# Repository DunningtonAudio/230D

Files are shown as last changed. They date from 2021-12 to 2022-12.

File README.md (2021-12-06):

# 230D
A triple envelope follower project

The 230D Triple Envelope Follower is designed to replicate the functionality of the Buchla 230A module using modern construction techniques and readily available parts. It is primarily based on the original circuit designed by Don Buchla, with the following additions/alterations:

* Proper current limiting implemented for pulse output LEDs, increasing LED life and preventing crosstalk between channels
* Pulse/gate output voltages adjusted to 10V/5V
* Pulse outputs are buffered, protecting the passive pulse generation network from the effects of loading when stacking one output to multiple destinations
* Pulse outputs are designed to allow stacking of multiple outputs to a single input, whilst also being able to drive a floating input low.

The repository contains:

* KiCad project files
* Schematic and build/calibration notes as PDF files
* Bill of Materials in ODS and PDF format
* Interactive webpage for matching BOM items to PCB locations

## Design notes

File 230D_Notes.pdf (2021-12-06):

230D Triple Envelope Follower

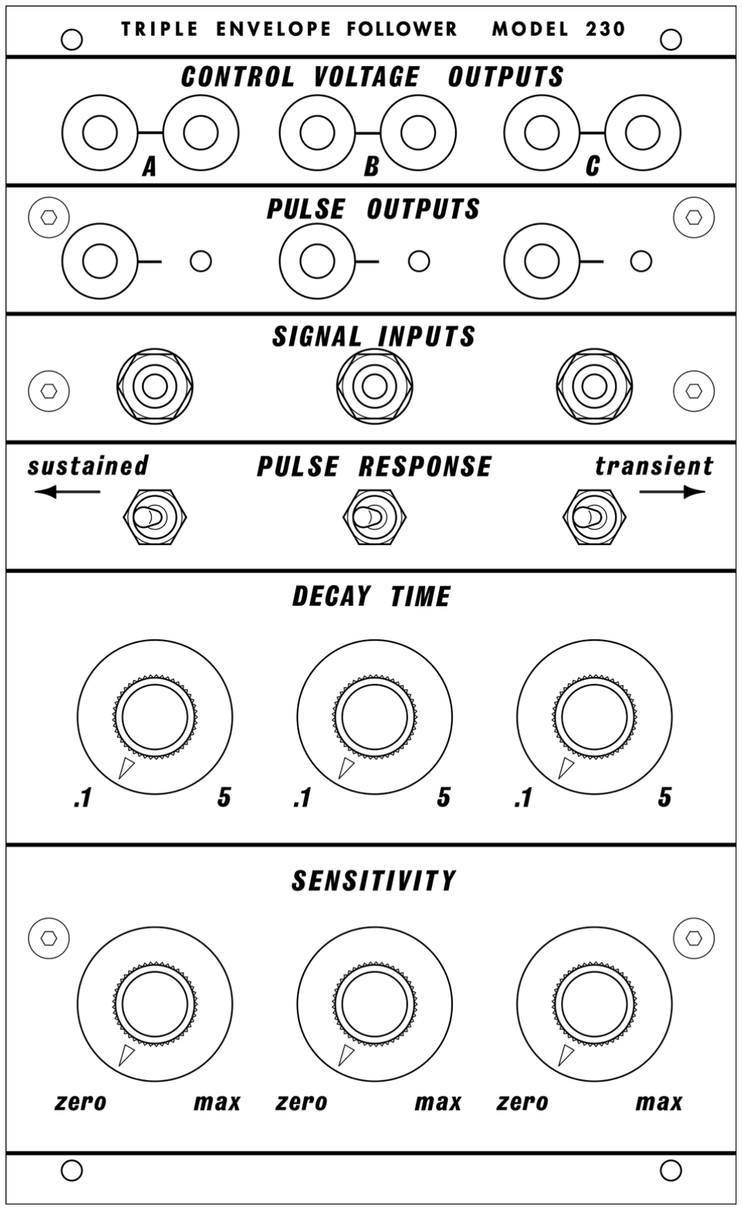
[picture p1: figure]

The 230D Triple Envelope Follower is designed to replicate the functionality of the Buchla 230A module using modern construction techniques and readily available parts. It is primarily based on the original circuit designed by Don Buchla, with the following additions/alterations:

- Proper current limiting implemented for pulse output LEDs, increasing LED life and preventing crosstalk between channels
- Pulse/gate output voltages adjusted to 10V/5V
- Pulse outputs are buffered, protecting the passive pulse generation network from the effects of loading when stacking one output to multiple destinations
- Pulse outputs are designed to allow stacking of multiple outputs to a single input, whilst also being able to drive a floating input low.

Build Notes:

** The 230D is designed to be suitable for hand assembly, but it is not recommended as a “learn surface mount” starting point. You should at a minimum have a temperature controlled soldering iron with a reasonably fine point and good quality solder 0.5mm diameter or finer. Some form of magnification may be beneficial for placing/inspecting fine pitch parts. **

It is recommended that the circuit board is populated in the following order:

- SOT-23 packages
- SOIC packages
- 0805 passives
- Trimmer potentiometers
- Tantalum chip capacitors
- Electrolytic capacitors
- Power wiring harness

Connectors should have their wire links attached and be mounted to the front panel, along with standoffs. Front panel potentiometers, switches and LEDs can then be loosely fitted into the PCB and the panel and PCB brought together before gently tightening the potentiometer and switch fixing nuts and soldering the panel components and connections.

Calibration procedure:

Equipment required:
- Power supply delivering +/- 15V and +12V, current limit at 20mA
- Signal generator
- DC Voltmeter
- Oscilloscope
1. Set front panel controls as follows:
- VR101/201/301 Sensitivity – Fully CCW
- VR102/202/302 Decay Time – Fully CCW
- SW101/201/301 Pulse Response – Transient
2. Set trimpots as follows (direction as viewed from the rear of the module):
- TR101/201/301 Offset – Centre
3. Apply power to the module and check for approx 10mA current draw on the +/- 15V rails, 0mA on the 12V rail.

The following steps should be repeated for each channel:

4. Allow the module to warm up. Connect the DC Voltmeter to the CV output of the channel under test and adjust the OFFSET trimpot for 0V DC at the output (note that the circuit is very sensitive, it may be beneficial to apply averaging to the reading).
5. Set the signal generator to produce a 1kHz, 1V peak to peak sine wave, connect this to the input of the channel under test, and monitor the CV output with the voltmeter. Adjust the sensitivity control for 10V DC at the CV output. Monitor the pulse output on the oscilloscope. Switch the pulse response to sustained and check that a brief ~10V pulse is produced before the output settles at a constant ~5V DC. Switch the response back to transient and check that the pulse output returns to 0V.
6. Monitor the control voltage output on the oscilloscope. Switch off the output of the signal generator and check that the fall time is approx. 100ms. Switch the signal generator back on, set the decay time control fully CW. Check that the CV output is still 10V DC and adjust the sensitivity if necessary. Switch off the signal generator and check that the fall time is approx. 5s.

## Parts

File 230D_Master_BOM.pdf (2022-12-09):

230D_1.2_Master

Reference | Quantity | Value | Footprint | Manufacturer | MPN | Supplier | Order Code | Description | Notes

PCB Mount
C105 C107 C205 C207 C305 C307 | 6 | 100p | C0805 | Yageo | CC0805JRNPO9BN101 | Mouser | 603-CC805JRNPO9BN101 | C0G, 50V, 5%
C106 C109 C206 C209 C306 C309 | 6 | 47n | C0805 | Yageo | CC0805JRNPO9BN221 | Mouser | 603-CC805KRX7R9BB473 | X7R, 50V, 10%
C102-103 C110-111 C202-203 C210-211 C302-303 C310-311 | 12 | 100n | C0805 | Yageo | CC0805KRX7R9BB104 | Mouser | 603-CC805KRX7R9BB104 | X7R, 50V, 10%
C101 C104 C201 C204 C301 C304 | 6 | 1u | CE4x5.8 | Panasonic | EEE-FC1V1R0AR | Mouser | 667-EEE-FC1V1R0AR | 35V, 20%, 105deg
C108 C208 C308 | 3 | 4u7 | C1210 (B) | AVX | TAJB475K035RNJ | Mouser | 581-TAJB475K035R | 35V, 10%, 125deg
C1 C2 C3 | 3 | 22u | CE5x5.8 | Panasonic | EEE-FK1V220AR | Mouser | 667-EEE-FK1V220AR | 35V, 20%, 105deg
D101 D201 D301 | 3 | SZMM3Z3V9ST1G | SOD-323 | On Semiconductor | SZMM3Z3V9ST1G | Mouser | 863-SZMM3Z3V9ST1G | Zener diode, 3.9V, 300mW
D102, D202, D302 | 3 | BAV99 | SOT-23-3 | On Semiconductor | BAV99LT1G | Mouser | 863-BAV99LT1G | Dual diode, series, 215mA
D103, D105, D203, D205, D303, D305 | 6 | BAS16 | SOT-23-3 | On Semiconductor | BAS16LT1G | Mouser | 863-BAS16LT1G | Diode, 200mA
D104, D204, D304 | 3 | Red_3mm | 3mm LED THT | Wurth Elektronik | 151031SS04000 | Mouser | 710-151031SS04000 | LED red 3mm 635nm 160mcd
L1 L2 L3 | 3 | 10u | L0805 | Taiyo Yuden | LBC2012T100K | Mouser | 963-LBC2012T100K | 1.2R, 200mA, 10%
Q101 Q201 Q301 | 3 | MMBT3904 | SOT-23-3 | On Semiconductor | MMBT3904LT1G | Mouser | 863-MMBT3904LT1G | NPN
R123 R129 R223 R229 R323 R329 | 6 | 1k | R0805 | Yageo | RC0805FR-071KL | Mouser | 603-RC0805FR-071KL | 150V, 125mW, 1%, 100PPM
R102 R124 R202 R224 R302 R324 | 6 | 4k7 | R0805 | Yageo | RC0805FR-074K7L | Mouser | 603-RC0805FR-074K7L | 150V, 125mW, 1%, 100PPM
R122 R125 R222 R225 R322 R325 | 6 | 6k8 | R0805 | Yageo | RC0805FR-076K8L | Mouser | 603-RC0805FR-076K8L | 150V, 125mW, 1%, 100PPM
R126 R128 R226 R228 R326 R328 | 6 | 10k | R0805 | Yageo | RC0805FR-0710KL | Mouser | 603-RC0805FR-0710KL | 150V, 125mW, 1%, 100PPM
R118 R127 R218 R227 R318 R327 | 6 | 11k | R0805 | Yageo | RC0805FR-0711KL | Mouser | 603-RC0805FR-0711KL | 150V, 125mW, 1%, 100PPM
R111 R119 R211 R219 R311 R319 | 6 | 15k | R0805 | Yageo | RC0805FR-0715KL | Mouser | 603-RC0805FR-0715KL | 150V, 125mW, 1%, 100PPM
R106-109 R112-113 R121 R206-209 R212-213 R221 R306-309 R312-313 R321 | 21 | 33k | R0805 | Yageo | RC0805FR-0733KL | Mouser | 603-RC0805FR-0733KL | 150V, 125mW, 1%, 100PPM
R114 R117 R214 R217 R314 R317 | 6 | 68k | R0805 | Yageo | RC0805FR-0768KL | Mouser | 603-RC0805FR-0768KL | 150V, 125mW, 1%, 100PPM
R120 R220 R320 | 3 | 100k | R0805 | Yageo | RC0805FR-07100KL | Mouser | 603-RC0805FR-07100KL | 150V, 125mW, 1%, 100PPM
R101 R201 R301 | 3 | 150k | R0805 | Yageo | RC0805FR-07150KL | Mouser | 603-RC0805FR-07150KL | 150V, 125mW, 1%, 100PPM
R105 R116 R205 R216 R305 R316 | 6 | 330k | R0805 | Yageo | RC0805FR-07330KL | Mouser | 603-RC0805FR-07330KL | 150V, 125mW, 1%, 100PPM
R115 R215 R315 | 3 | 4M7 | R0805 | Yageo | RC0805FR-074M7L | Mouser | 603-RC0805FR-074M7L | 150V, 125mW, 1%, 100PPM
R103 R110 R203 R210 R303 R310 | 6 | 10M | R0805 | Yageo | RC0805FR-0710ML | Mouser | 603-RC0805FR-0710ML | 150V, 125mW, 1%, 100PPM
R104, R204, R304 | 3 | 22M | R0805 | Yageo | RC0805JR-0722ML | Mouser | 603-RC0805JR-0722ML | 150V, 125mW, 5%, 200PPM
SW101 SW201 SW301 | 3 | SPDT_ON-ON | M201X | NKK | M2012SS1W01 | Mouser | 633-M201201 | Toggle switch SPDT On-On
TR101 TR201 TR301 | 3 | 5k | 3314J | Bourns | 3314J-1-502E | Mouser | 652-3314J-1-502E | 500V,250mW, 20%, 100PPM
U101, U201, U301 | 3 | LM348 | SOIC14 | Texas Instruments | LM348DR | Mouser | 595-LM348DR | Quad operational amplifier, BJT input
U102, U202, U302 | 3 | LM321 | SOT-23-5 | Texas Instruments | LM321MF/NOPB | Mouser | 926-LM321MF/NOPB | Operational amplifier, BJT input
VR101 VR201 VR301 | 3 | 50kA | RV16AF-41-(L)R1-XXX | Alpha | RV16AF-41-15R1-503A | Small Bear | 1011 A50K | 16mm RA PCB mount potentiometer | Snap off locating lug
VR102 VR202 VR302 | 3 | 1MA | RV16AF-41-(L)R1-XXX | Alpha | RV16AF-41-15R1-105A | Small Bear | 1011 A1M | 16mm RA PCB mount potentiometer | Snap off locating lug
| 6 | | | McMaster-Carr | 93925A422 | McMaster | 93925A422 | M7 Shakeproof Washer | Fit between 16mm potentiometers and panel. Order code is for 100.

Panel Mount

J103-104 J203-204 J303-304 | 6 | CV Outputs | Johnson | 108-0910-001 | Mouser | 530-108-0910-1 | Blue banana jack
J102 J202 J302 | 3 | Pulse Outputs | Johnson | 108-0902-001 | Mouser | 530-108-0902-1 | Red banana jack
J101 J201 J301 | 3 | Audio Inputs | Switchcraft | 41 | Mouser | 502-41 | Tinijax
24awg wire black 25mm length | 3 | | Alpha Wire | 892419 BK005 | Mouser | 602-892419-100-02 | Wiring to audio shields | Strip 4mm each end. Order code is for 30.5m reel.
24awg wire white 25mm length | 3 | | Alpha Wire | 892419 WH005 | Mouser | 602-892419-100-01 | Wiring to audio inputs | Strip 4mm each end. Order code is for 30.5m reel.
24awg wire blue 25mm length | 6 | | Alpha Wire | 892419 BL005 | Mouser | 602-892419-100-06 | Wiring to CV outputs | Strip 4mm each end. Order code is for 30.5m reel.
24awg wire red 25mm length | 3 | | Alpha Wire | 892419 RD005 | Mouser | 602-892419-100-03 | Wiring to pulse outputs | Strip 4mm each end. Order code is for 30.5m reel.

Hardware & Misc

PCB | 1 | | Dunnington Audio | | thebeast.co.uk | http://thebeast.co.uk/?product=230d-triple-envelope-follower-pcb
Front panel | 1 | | The Beast | | thebeast.co.uk | http://thebeast.co.uk/?product=buchla-style-230-panel-reprint
M3x14mm F-F Standoff | 6 | | Harwin | R30-1001402 | Mouser | 855-R30-1001402
M3x6mm Philips CSK | 6 | | McMaster-Carr | 91801A151 | McMaster | 91801A151 | | Panel to standoff fixing. Order code is for 100.
M3x6mm Philips Pan SEMS | 6 | | McMaster-Carr | 90460A101 | McMaster | 90460A101 | | PCB to standoff fixing. Order code is for 25.
M3 Shakeproof Washer | 6 | | McMaster-Carr | 93925A417 | McMaster | 93925A417 | | Fit between standoffs and panel. Order code is for 100.
Small Skirted Knob | 6 | | Rogan | RB67-0-SK | Thonk | https://www.thonk.co.uk/shop/rogan-buchla/ | | Fit on all 16mm potentiometers
Switch Cap Red | 3 | | Thonk | | Thonk | https://www.thonk.co.uk/shop/switchcaps-mini/ | | Fit on SW101, SW201, SW301
J1 | 1 | Power | EDAC | 306-010-500-102 | Mouser | 587-306-50-010 | 10P edge connector, 3.96mm
| 1 | | EDAC | 338-240-328 | Mouser | 587-338-240-328 | Polarizing key | Fit in position 7 of power EDAC
20awg wire black 350mm length | 1 | Q | Alpha Wire | 892019 BK005 | Mouser | 602-892019-100-02 | | EDAC position 1. Order code is for 30.5m reel.
20awg wire white 350mm length | 1 | -15V | Alpha Wire | 892019 WH005 | Mouser | 602-892019-100-01 | | EDAC position 2. Order code is for 30.5m reel.
20awg wire red 350mm length | 1 | +15V | Alpha Wire | 892019 RD005 | Mouser | 602-892019-100-03 | | EDAC position 3. Order code is for 30.5m reel.
20awg wire green 350mm length | 1 | +12V | Alpha Wire | 892019 GR005 | Mouser | 602-892019-100-04 | | EDAC position 4. Order code is for 30.5m reel.
20awg wire brown 350mm length | 1 | N | Alpha Wire | 892019 BR005 | Mouser | 602-892019-100-07 | | EDAC position 6. Order code is for 30.5m reel.
Expandable Sleeving 6mm 300mm | 1 | | Alpha Wire | GRP1301/4 BK007 | Mouser | 602-130014-50BK | | Fit over power cabling. Order code is for 15.25m reel.
Heatshrink 6.35mm 40mm length | 2 | | Alpha Wire | FIT221V1/4 BK103 | Mouser | 602-221V014-4 | | Fit at each end of expandable sleeving
Heatshrink 3.18mm 12mm length | 5 | | Alpha Wire | FIT221V1/8 BK103 | Mouser | 602-221V018-4 | | Fit over terminated EDAC contacts
Cable ties | 2 | | Panduit | PLT.7M-M | Mouser | 644-PLT.7M-M | | Secure power cabling to PCB and EDAC

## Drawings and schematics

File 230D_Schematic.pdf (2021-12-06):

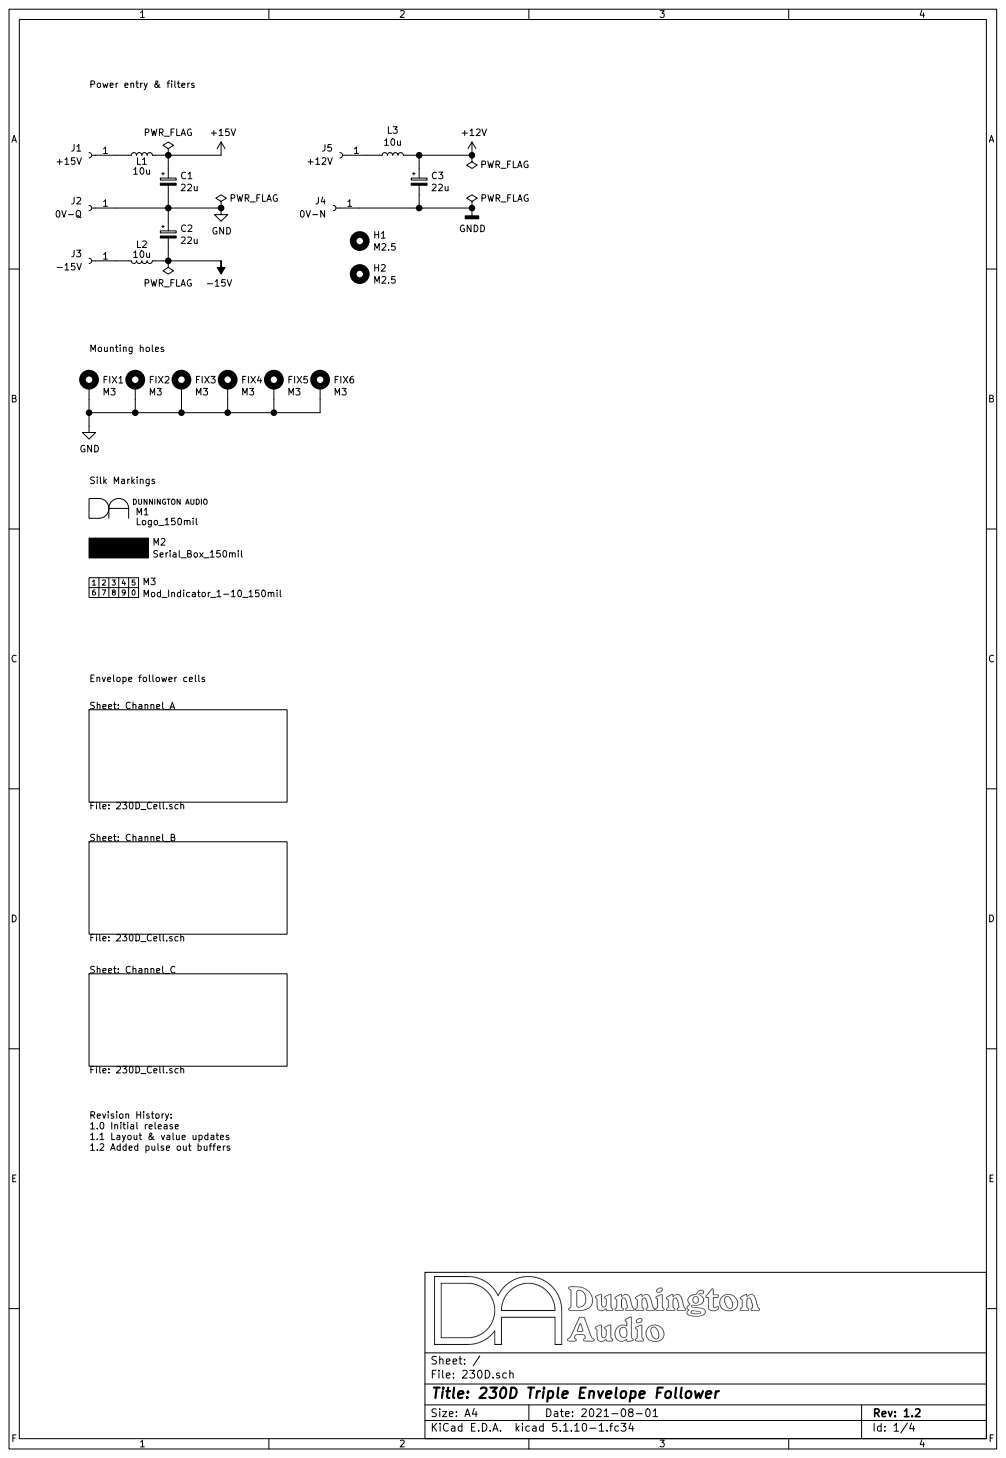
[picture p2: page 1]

Id: 1/4 Title: 230D Triple Envelope Follower File: 230D.sch Sheet: / Sheet: Channel_C

Revision History: 1.0 Initial release

1.1 Layout & value updates
1.2 Added pulse out buffers

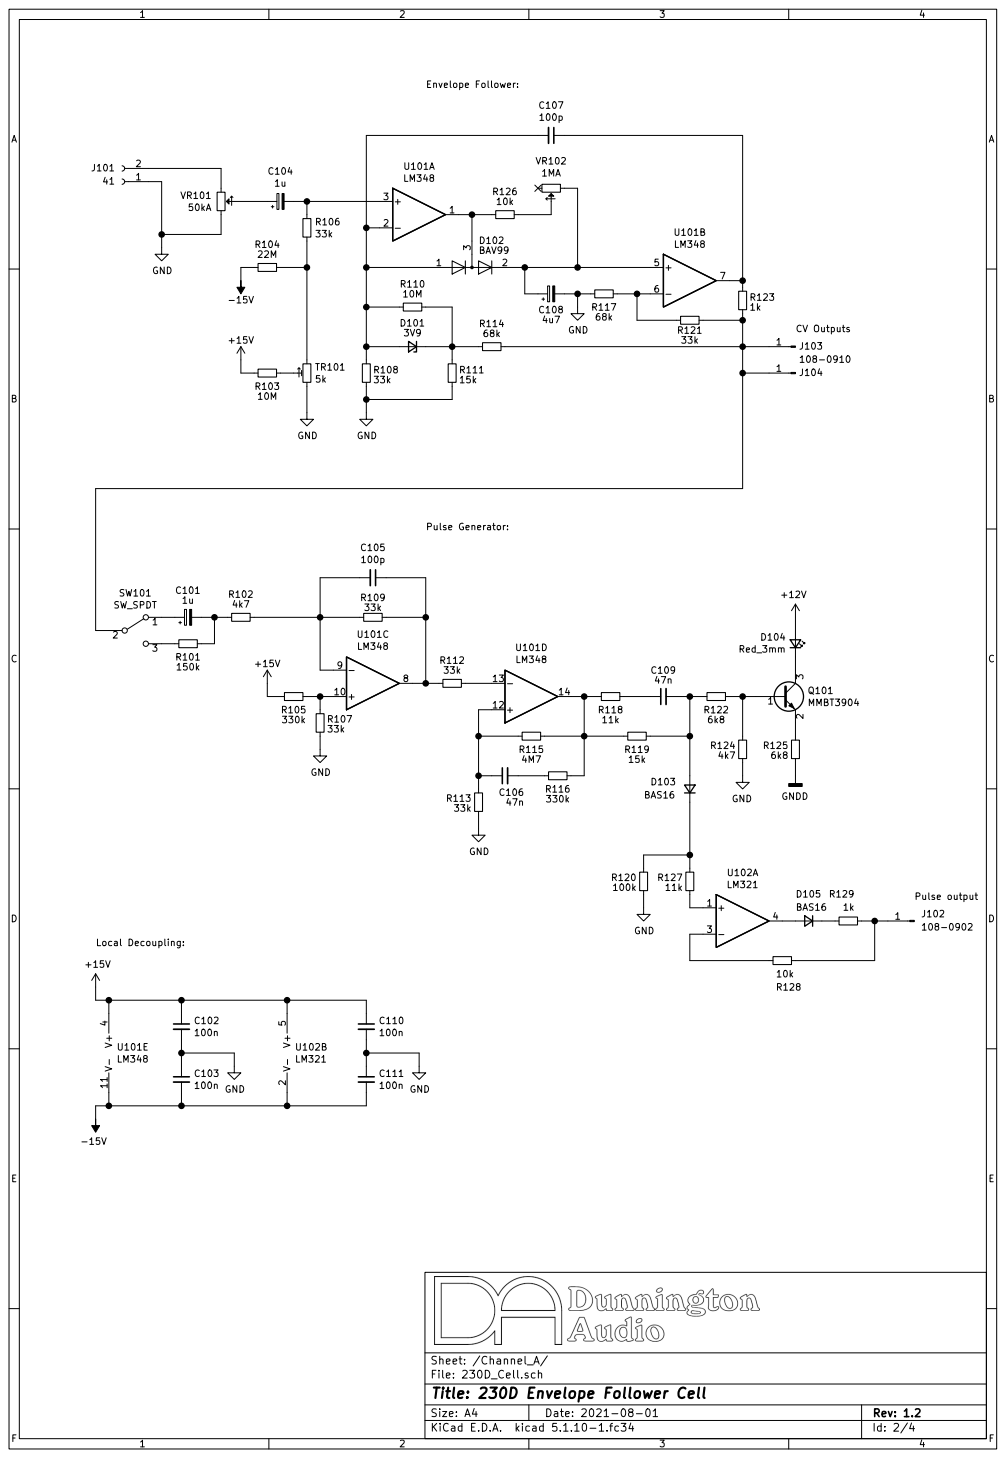
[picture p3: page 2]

Sheet: /Channel_A/
File: 230D_Cell.sch
Id: 2/4 Title: 230D Envelope Follower Cell

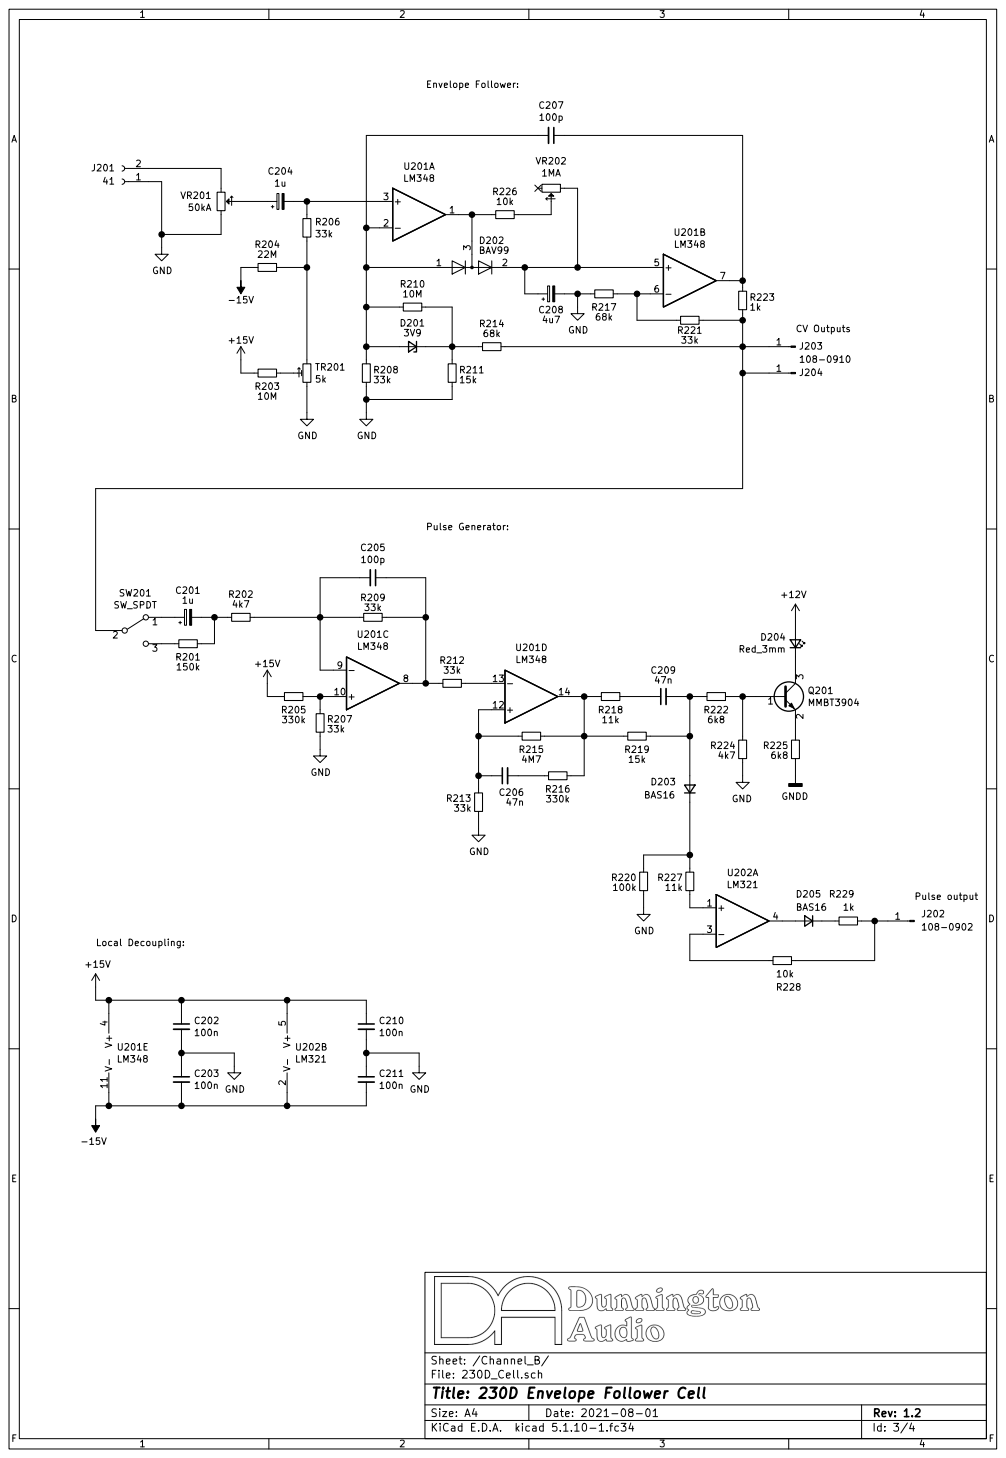
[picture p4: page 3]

Sheet: /Channel_B/
Id: 3/4 Title: 230D Envelope Follower Cell

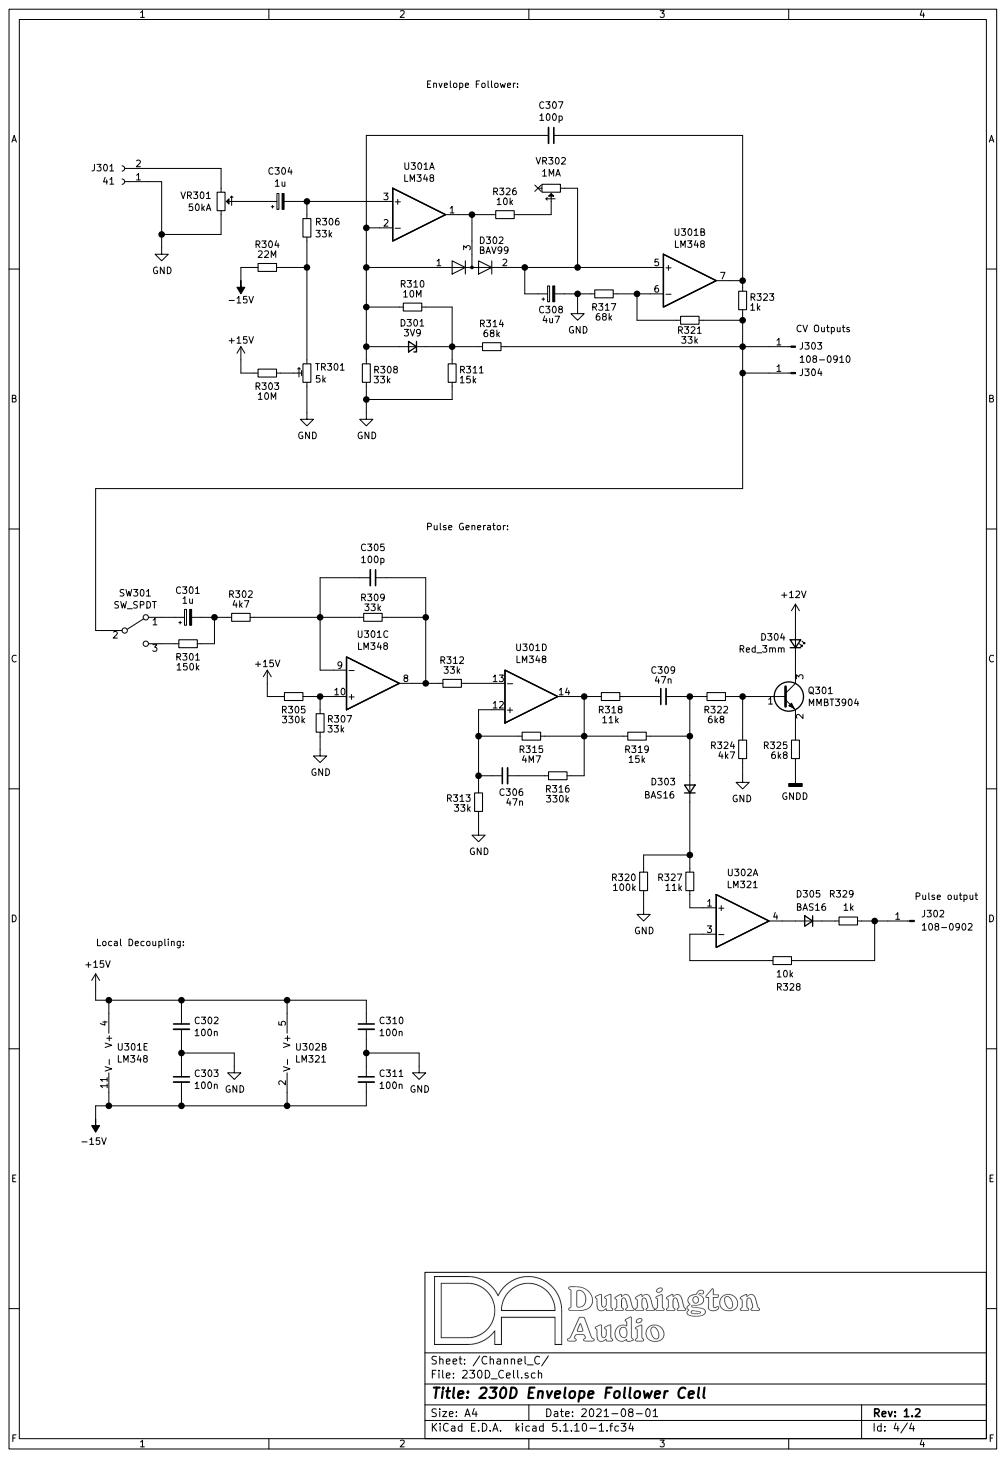
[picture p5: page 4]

Sheet: /Channel_C/
Id: 4/4 Title: 230D Envelope Follower Cell

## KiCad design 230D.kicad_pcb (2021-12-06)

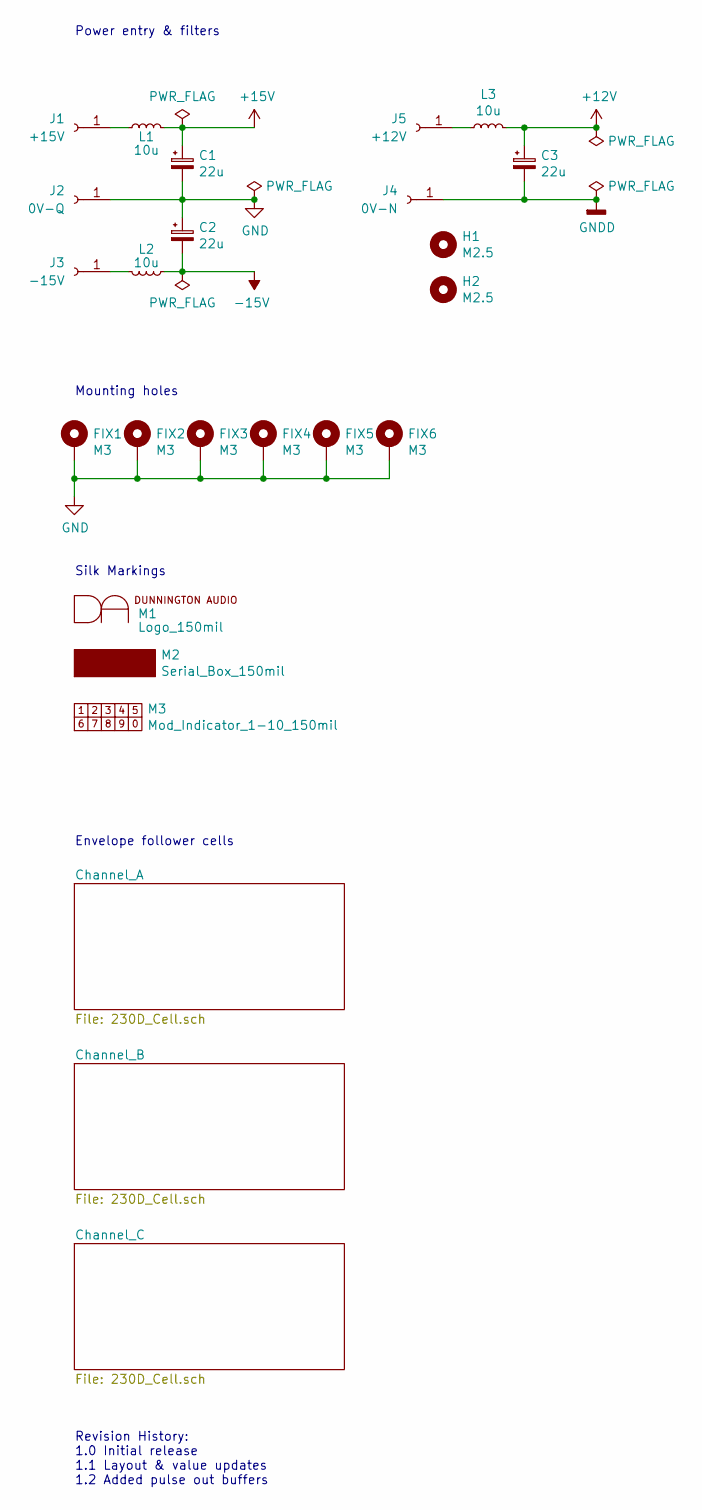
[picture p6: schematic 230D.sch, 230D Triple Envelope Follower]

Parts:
C1, C2, C3: 22u; CP_Elec_5x5.3
FIX1, FIX2, FIX3, FIX4, FIX5, FIX6: M3; MountingHole_3.2mm_M3_Pad_Via
H1, H2: M2.5; MountingHole_2.5mm
J1: +15V; SolderWirePad_1x01_Drill1.2mm
J2: 0V-Q; SolderWirePad_1x01_Drill1.2mm
J3: -15V; SolderWirePad_1x01_Drill1.2mm
J4: 0V-N; SolderWirePad_1x01_Drill1.2mm
J5: +12V; SolderWirePad_1x01_Drill1.2mm
L1, L2, L3: 10u; L_0805_2012Metric
M1: Logo_150mil
M2: Serial_Box_150mil
M3: Mod_Indicator_1-10_150mil

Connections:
+12V: C3.1, L3.2; also elsewhere on the board
+15V: C1.1, L1.2; also elsewhere on the board
-15V: C2.2, L2.1; also elsewhere on the board
GND: C1.2, C2.1, FIX1.1, FIX2.1, FIX3.1, FIX4.1, FIX5.1, FIX6.1, J2.1; also elsewhere on the board
GNDD: C3.2, J4.1; also elsewhere on the board
unnamed: J1.1, L1.1
unnamed: J3.1, L2.2
unnamed: J5.1, L3.1

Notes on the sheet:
Power entry & filters
Mounting holes
Silk Markings
Envelope follower cells
Revision History: 1.0 Initial release 1.1 Layout & value updates 1.2 Added pulse out buffers

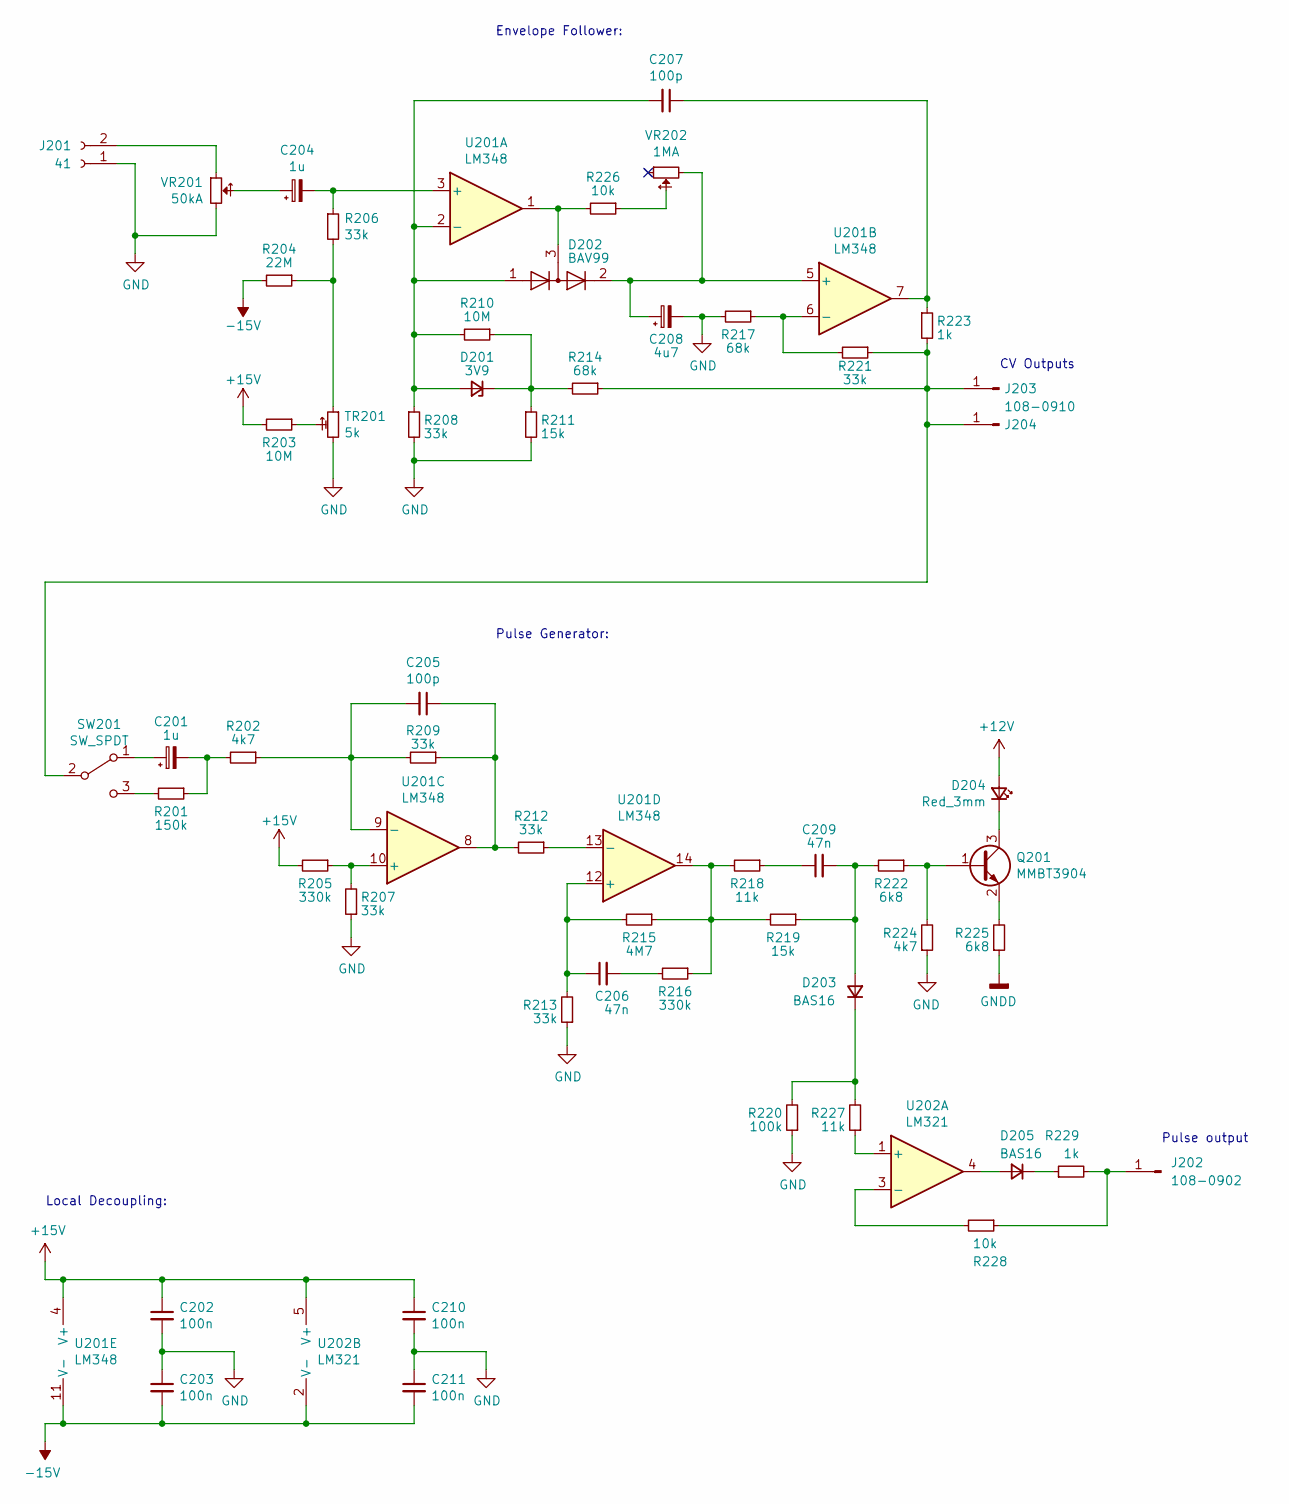
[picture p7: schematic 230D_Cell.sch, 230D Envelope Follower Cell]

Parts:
C101, C104: 1u; CP_Elec_4x5.3
C102, C103, C110, C111: 100n; C_0805_2012Metric
C105, C107: 100p; C_0805_2012Metric
C106, C109: 47n; C_0805_2012Metric
C108: 4u7; CP_EIA-3528-21_Kemet-B
D101: 3V9; D_SOD-323
D102: BAV99; SOT-23
D103, D105: BAS16; SOT-23
D104: Red_3mm; LED_D3.0mm
J101: 41; Switchcraft_41
J102: 108-0902; Johnson_108-09XX-001
J103, J104: 108-0910; Johnson_108-09XX-001
Q101: MMBT3904; SOT-23
R101: 150k; R_0805_2012Metric
R102, R124: 4k7; R_0805_2012Metric
R103, R110: 10M; R_0805_2012Metric
R104: 22M; R_0805_2012Metric
R105, R116: 330k; R_0805_2012Metric
R106, R107, R108, R109, R112, R113, R121: 33k; R_0805_2012Metric
R111, R119: 15k; R_0805_2012Metric
R114, R117: 68k; R_0805_2012Metric
R115: 4M7; R_0805_2012Metric
R118, R127: 11k; R_0805_2012Metric
R120: 100k; R_0805_2012Metric
R122, R125: 6k8; R_0805_2012Metric
R123, R129: 1k; R_0805_2012Metric
R126, R128: 10k; R_0805_2012Metric
SW101: SW_SPDT; M201xSS1x01
TR101: 5k; Potentiometer_Bourns_3314J_Vertical
U101: LM348; SOIC-14_3.9x8.7mm_P1.27mm
U102: LM321; SOT-23-5
VR101: 50kA; RV16AF-41-(L)R1-XXX
VR102: 1MA; RV16AF-41-(L)R1-XXX

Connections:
+12V: D104.2 (A); also elsewhere on the board
+15V: C102.1, C110.1, R103.2, R105.2, U101.4 (V+), U102.5 (V+); also elsewhere on the board
-15V: C103.2, C111.2, R104.2, U101.11 (V-), U102.2 (V-); also elsewhere on the board
GND: C102.2, C103.1, C108.2, C110.2, C111.1, J101.1, R107.1, R108.2, R111.2, R113.1, R117.2, R120.1, R124.1, TR101.1, VR101.1; also elsewhere on the board
GNDD: R125.1; also elsewhere on the board
unnamed: C101.1, SW101.1 (A)
unnamed: C101.2, R101.1, R102.2
unnamed: C104.1, VR101.2
unnamed: C104.2, R106.1, U101.3 (+)
unnamed: C105.1, R109.1, R112.2, U101.8
unnamed: C105.2, R102.1, R109.2, U101.9 (-)
unnamed: C106.1, R113.2, R115.2, U101.12 (+)
unnamed: C106.2, R116.2
unnamed: C107.1, R123.1, U101.7
unnamed: C107.2, D101.2 (A), D102.1 (K), R108.1, R110.2, U101.2 (-)
unnamed: C108.1, D102.2 (A), U101.5 (+), VR102.1
unnamed: C109.1, R118.1
unnamed: C109.2, D103.1 (A), R119.1, R122.2
unnamed: D101.1 (K), R110.1, R111.1, R114.2
unnamed: D102.3 (K), R126.2, U101.1
unnamed: D103.3 (K), R120.2, R127.2
unnamed: D104.1 (K), Q101.3 (C)
unnamed: D105.1 (A), U102.4
unnamed: D105.3 (K), R129.1
unnamed: J101.2, VR101.3
unnamed: J102.1, R128.1, R129.2
unnamed: J103.1, J104.1, R114.1, R121.1, R123.2, SW101.2 (B)
unnamed: Q101.1 (B), R122.1, R124.2
unnamed: Q101.2 (E), R125.2
unnamed: R101.2, SW101.3 (C)
unnamed: R103.1, TR101.2
unnamed: R104.1, R106.2, TR101.3
unnamed: R105.1, R107.2, U101.10 (+)
unnamed: R112.1, U101.13 (-)
unnamed: R115.1, R116.1, R118.2, R119.2, U101.14
unnamed: R117.1, R121.2, U101.6 (-)
unnamed: R126.1, VR102.2
unnamed: R127.1, U102.1 (+)
unnamed: R128.2, U102.3 (-)

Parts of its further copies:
C201, C204, C301, C304: 1u; CP_Elec_4x5.3
C202, C203, C210, C211, C302, C303, C310, C311: 100n; C_0805_2012Metric
C205, C207, C305, C307: 100p; C_0805_2012Metric
C206, C209, C306, C309: 47n; C_0805_2012Metric
C208, C308: 4u7; CP_EIA-3528-21_Kemet-B
D201, D301: 3V9; D_SOD-323
D202, D302: BAV99; SOT-23
D203, D205, D303, D305: BAS16; SOT-23
D204, D304: Red_3mm; LED_D3.0mm
J201, J301: 41; Switchcraft_41
J202, J302: 108-0902; Johnson_108-09XX-001
J203, J204, J303, J304: 108-0910; Johnson_108-09XX-001
Q201, Q301: MMBT3904; SOT-23
R201, R301: 150k; R_0805_2012Metric
R202, R224, R302, R324: 4k7; R_0805_2012Metric
R203, R210, R303, R310: 10M; R_0805_2012Metric
R204, R304: 22M; R_0805_2012Metric
R205, R216, R305, R316: 330k; R_0805_2012Metric
R206, R207, R208, R209, R212, R213, R221, R306, R307, R308, R309, R312, R313, R321: 33k; R_0805_2012Metric
R211, R219, R311, R319: 15k; R_0805_2012Metric
R214, R217, R314, R317: 68k; R_0805_2012Metric
R215, R315: 4M7; R_0805_2012Metric
R218, R227, R318, R327: 11k; R_0805_2012Metric
R220, R320: 100k; R_0805_2012Metric
R222, R225, R322, R325: 6k8; R_0805_2012Metric
R223, R229, R323, R329: 1k; R_0805_2012Metric
R226, R228, R326, R328: 10k; R_0805_2012Metric
SW201, SW301: SW_SPDT; M201xSS1x01
TR201, TR301: 5k; Potentiometer_Bourns_3314J_Vertical
U201, U301: LM348; SOIC-14_3.9x8.7mm_P1.27mm
U202, U302: LM321; SOT-23-5
VR201, VR301: 50kA; RV16AF-41-(L)R1-XXX
VR202, VR302: 1MA; RV16AF-41-(L)R1-XXX

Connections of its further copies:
+12V: D204.2 (A), D304.2 (A); also elsewhere on the board
+15V: C202.1, C210.1, C302.1, C310.1, R203.2, R205.2, R303.2, R305.2, U201.4 (V+), U202.5 (V+), U301.4 (V+), U302.5 (V+); also elsewhere on the board
-15V: C203.2, C211.2, C303.2, C311.2, R204.2, R304.2, U201.11 (V-), U202.2 (V-), U301.11 (V-), U302.2 (V-); also elsewhere on the board
GND: C202.2, C203.1, C208.2, C210.2, C211.1, C302.2, C303.1, C308.2, C310.2, C311.1, J201.1, J301.1, R207.1, R208.2, R211.2, R213.1, R217.2, R220.1, R224.1, R307.1, R308.2, R311.2, R313.1, R317.2, R320.1, R324.1, TR201.1, TR301.1, VR201.1, VR301.1; also elsewhere on the board
GNDD: R225.1, R325.1; also elsewhere on the board
unnamed: C201.1, SW201.1 (A)
unnamed: C201.2, R201.1, R202.2
unnamed: C204.1, VR201.2
unnamed: C204.2, R206.1, U201.3 (+)
unnamed: C205.1, R209.1, R212.2, U201.8
unnamed: C205.2, R202.1, R209.2, U201.9 (-)
unnamed: C206.1, R213.2, R215.2, U201.12 (+)
unnamed: C206.2, R216.2
unnamed: C207.1, R223.1, U201.7
unnamed: C207.2, D201.2 (A), D202.1 (K), R208.1, R210.2, U201.2 (-)
unnamed: C208.1, D202.2 (A), U201.5 (+), VR202.1
unnamed: C209.1, R218.1
unnamed: C209.2, D203.1 (A), R219.1, R222.2
unnamed: C301.1, SW301.1 (A)
unnamed: C301.2, R301.1, R302.2
unnamed: C304.1, VR301.2
unnamed: C304.2, R306.1, U301.3 (+)
unnamed: C305.1, R309.1, R312.2, U301.8
unnamed: C305.2, R302.1, R309.2, U301.9 (-)
unnamed: C306.1, R313.2, R315.2, U301.12 (+)
unnamed: C306.2, R316.2
unnamed: C307.1, R323.1, U301.7
unnamed: C307.2, D301.2 (A), D302.1 (K), R308.1, R310.2, U301.2 (-)
unnamed: C308.1, D302.2 (A), U301.5 (+), VR302.1
unnamed: C309.1, R318.1
unnamed: C309.2, D303.1 (A), R319.1, R322.2
unnamed: D201.1 (K), R210.1, R211.1, R214.2
unnamed: D202.3 (K), R226.2, U201.1
unnamed: D203.3 (K), R220.2, R227.2
unnamed: D204.1 (K), Q201.3 (C)
unnamed: D205.1 (A), U202.4
unnamed: D205.3 (K), R229.1
unnamed: D301.1 (K), R310.1, R311.1, R314.2
unnamed: D302.3 (K), R326.2, U301.1
unnamed: D303.3 (K), R320.2, R327.2
unnamed: D304.1 (K), Q301.3 (C)
unnamed: D305.1 (A), U302.4
unnamed: D305.3 (K), R329.1
unnamed: J201.2, VR201.3
unnamed: J202.1, R228.1, R229.2
unnamed: J203.1, J204.1, R214.1, R221.1, R223.2, SW201.2 (B)
unnamed: J301.2, VR301.3
unnamed: J302.1, R328.1, R329.2
unnamed: J303.1, J304.1, R314.1, R321.1, R323.2, SW301.2 (B)
unnamed: Q201.1 (B), R222.1, R224.2
unnamed: Q201.2 (E), R225.2
unnamed: Q301.1 (B), R322.1, R324.2
unnamed: Q301.2 (E), R325.2
unnamed: R201.2, SW201.3 (C)
unnamed: R203.1, TR201.2
unnamed: R204.1, R206.2, TR201.3
unnamed: R205.1, R207.2, U201.10 (+)
unnamed: R212.1, U201.13 (-)
unnamed: R215.1, R216.1, R218.2, R219.2, U201.14
unnamed: R217.1, R221.2, U201.6 (-)
unnamed: R226.1, VR202.2
unnamed: R227.1, U202.1 (+)
unnamed: R228.2, U202.3 (-)
unnamed: R301.2, SW301.3 (C)
unnamed: R303.1, TR301.2
unnamed: R304.1, R306.2, TR301.3
unnamed: R305.1, R307.2, U301.10 (+)
unnamed: R312.1, U301.13 (-)
unnamed: R315.1, R316.1, R318.2, R319.2, U301.14
unnamed: R317.1, R321.2, U301.6 (-)
unnamed: R326.1, VR302.2
unnamed: R327.1, U302.1 (+)
unnamed: R328.2, U302.3 (-)

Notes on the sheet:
Envelope Follower:
Pulse Generator:
Local Decoupling:
CV Outputs
Pulse output

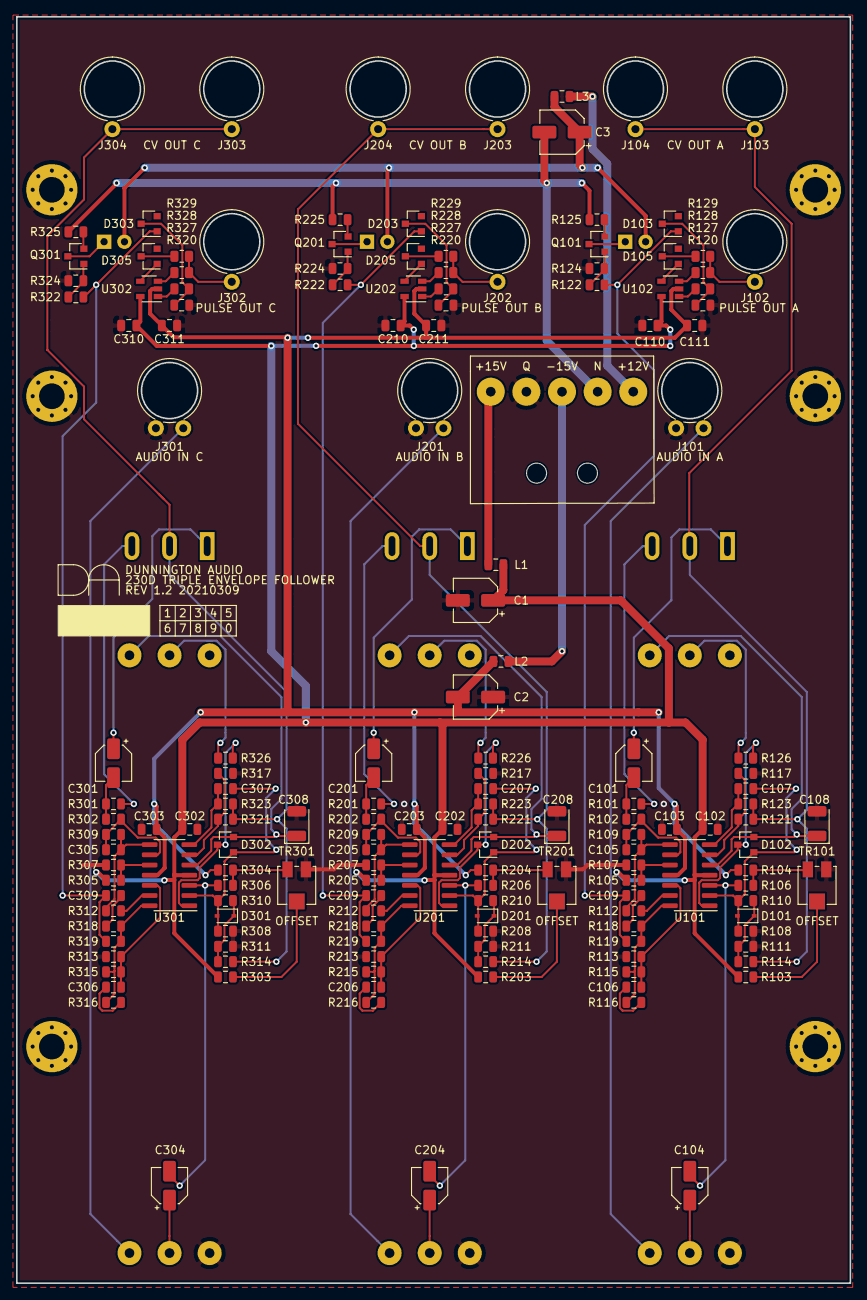
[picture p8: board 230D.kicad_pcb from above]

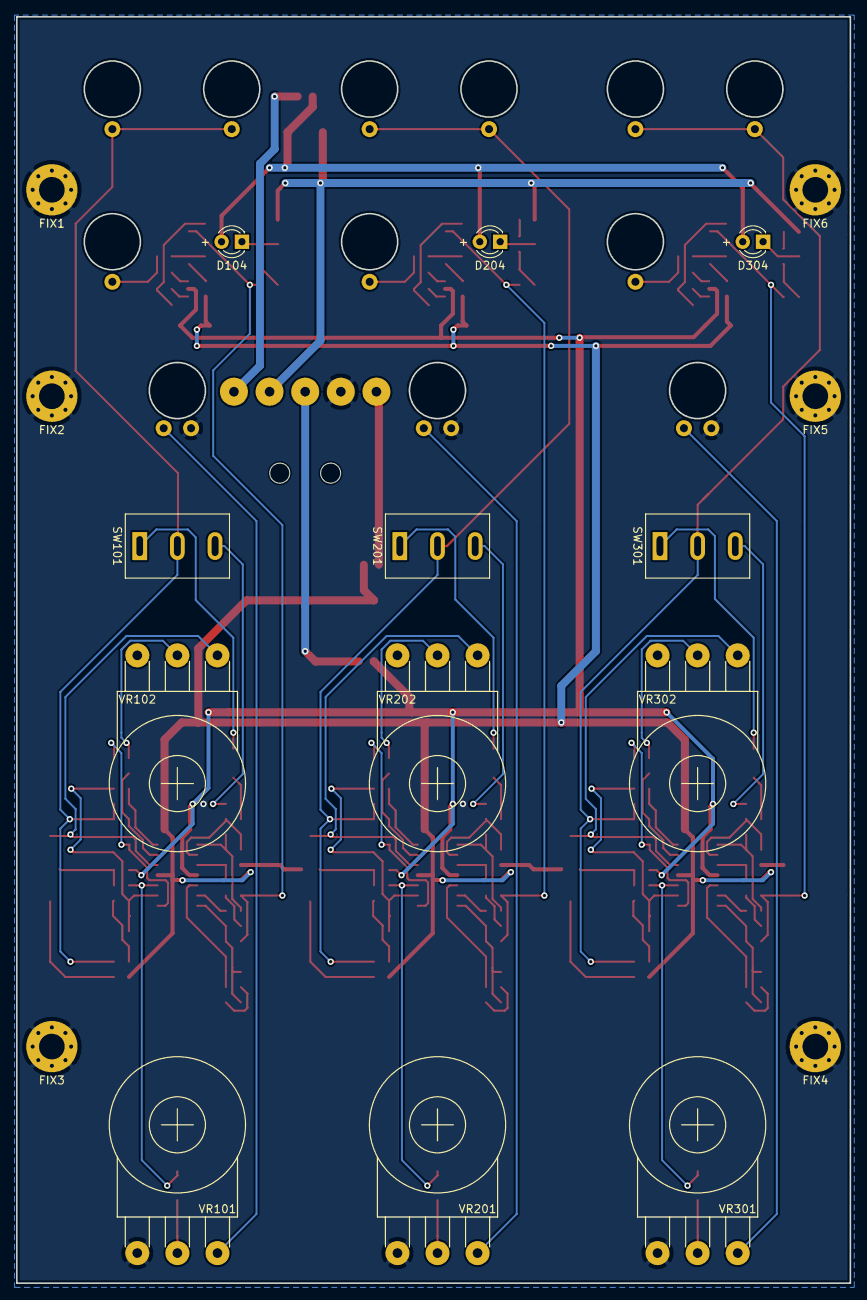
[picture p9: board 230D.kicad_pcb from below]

Board: 2 copper layers, 104.0 x 158.0 mm, 190 parts (18 on the bottom side), 110 nets.

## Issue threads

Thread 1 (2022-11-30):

230D 11k resistor - wrong Mouser number

danielanez, 2022-11-30:
The PDF Bom file for 230D gives a wrong number for the 11k resistor. It gives you a 390Ohm one.

DunningtonAudio, 2022-12-09:
Fixed, thanks!

Closed 2022-12-09.
